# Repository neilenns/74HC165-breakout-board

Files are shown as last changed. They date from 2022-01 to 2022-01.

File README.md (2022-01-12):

# 74HC165 breakout board

This PCB provides access to the inputs of four serially connected 74HC165s. It's perfect for expanding the number
of inputs available on smaller Arduinos like the Pro Micro or Nano when building flight simulator components
that interact with [MobiFlight](http://www.mobiflight.com).

74HC165-breakout-board-3D_top

## Ordering from JLCPCB

These boards are ready to order from JLCPCB with their SMT fabrication service. You'll receive boards with all
the components soldered on except for the pin headers which you add yourself.

### Setting up the PCB details

1. Download and unpack `74HC165-breakout-board-JLCPCB.zip` from [the latest release](https://github.com/neilenns/74HC165-breakout-board/releases/latest). You will wind up with three files:

   - `74HC165-breakout-board-JLCPCB.zip`
   - `74HC165-breakout-board_bom_jlc.csv`
   - `74HC165-breakout-board_cpl_jlc.csv`

2. Start a new order with JLCPCB and upload the `74HC165-breakout-board-JLCPCB.zip` file for the Gerbers.
3. Set the `Surface Finish` option to `LeadFree HASL-RoHS`.
4. Set the `Remove Order Number` option to `Specify a location`.
5. Enable the `SMT Assembly` option.
6. Make sure `Assemble top side` is selected.
7. Set the `Tooling holes` option to `Added by customer`.
8. Agree to the terms and select the `Confirm` button.

### Setting up the SMT assembly

1. Upload the `74HC165-breakout-board_bom_jlc.csv` file for the BOM file.
2. Upload the `74HC165-breakout-board_bom_jlc` file for the CPL file.
3. Select the `Next` button.
4. Verify three parts are detected: `4D03WGJ0103T5E`, `CC0805KRX7R9BB104` and `74HC165D,653`. If you are ordering the default 5 boards
   you'll see order quantities of 50 for each part due to minimum part count requirements. This is expected.
5. Select the `Next` button.
6. Select the `Save to cart` button.

The total cost for five green PCBs with all parts assembled should be around $16.

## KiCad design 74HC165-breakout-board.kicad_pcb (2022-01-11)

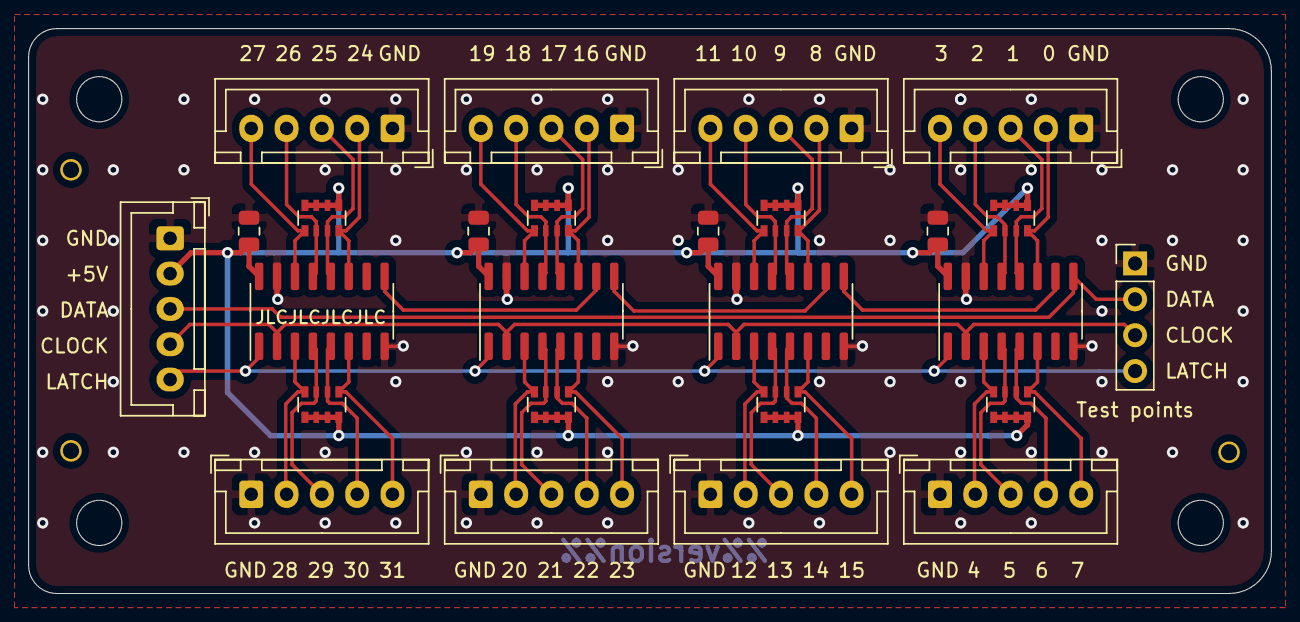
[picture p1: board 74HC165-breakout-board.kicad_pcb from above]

Board: 2 copper layers, 88.0 x 40.0 mm, 33 parts (0 on the bottom side), 40 nets.

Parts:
C1, C2, C3, C4: 100nF; C_0805_2012Metric
H1, H2, H3, H4: MountingHole; MountingHole_3.2mm_M3
H5, H6, H7: MountingHole; JLCPCB_Tooling_Hole
J1, J2, J3, J4, J5, J6, J7, J8, J9: Conn_01x05; JST_XH_B5B-XH-A_1x05_P2.50mm_Vertical
J10: Conn_01x04; PinHeader_1x04_P2.54mm_Vertical
RN1, RN2, RN3, RN4, RN5, RN6, RN7, RN8: R_Pack04; R_Array_Convex_4x0603
U1, U2, U3, U4: 74HC165; SOIC-16_3.9x9.9mm_P1.27mm

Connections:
+5V: C1.1, C2.1, C3.1, C4.1, J1.2, RN1.1, RN1.2, RN1.3, RN1.4, RN2.1, RN2.2, RN2.3, RN2.4, RN3.1, RN3.2, RN3.3, RN3.4, RN4.1, RN4.2, RN4.3, RN4.4, RN5.1, RN5.2, RN5.3, RN5.4, RN6.1, RN6.2, RN6.3, RN6.4, RN7.1, RN7.2, RN7.3, RN7.4, RN8.1, RN8.2, RN8.3, RN8.4, U1.16, U2.16, U3.16, U4.16
/74HC165/A: J2.2, RN1.8, U1.11
/74HC165/B: J2.3, RN1.7, U1.12
/74HC165/C: J2.4, RN1.6, U1.13
/74HC165/D: J2.5, RN1.5, U1.14
/74HC165/E: J3.2, RN2.8, U1.3
/74HC165/F: J3.3, RN2.7, U1.4
/74HC165/G: J3.4, RN2.6, U1.5
/74HC165/H: J3.5, RN2.5, U1.6
/74HC165/QH: U1.9, U2.10
/sheet61DDC3C2/A: J6.2, RN5.8, U3.11
/sheet61DDC3C2/B: J6.3, RN5.7, U3.12
/sheet61DDC3C2/C: J6.4, RN5.6, U3.13
/sheet61DDC3C2/D: J6.5, RN5.5, U3.14
/sheet61DDC3C2/E: J7.2, RN6.8, U3.3
/sheet61DDC3C2/F: J7.3, RN6.7, U3.4
/sheet61DDC3C2/G: J7.4, RN6.6, U3.5
/sheet61DDC3C2/H: J7.5, RN6.5, U3.6
/sheet61DDC3C2/QH: U3.9, U4.10
/sheet61DDC5EC/A: J8.2, RN7.8, U4.11
/sheet61DDC5EC/B: J8.3, RN7.7, U4.12
/sheet61DDC5EC/C: J8.4, RN7.6, U4.13
/sheet61DDC5EC/D: J8.5, RN7.5, U4.14
/sheet61DDC5EC/E: J9.2, RN8.8, U4.3
/sheet61DDC5EC/F: J9.3, RN8.7, U4.4
/sheet61DDC5EC/G: J9.4, RN8.6, U4.5
/sheet61DDC5EC/H: J9.5, RN8.5, U4.6
/sheet61DDC16C/A: J4.2, RN3.8, U2.11
/sheet61DDC16C/B: J4.3, RN3.7, U2.12
/sheet61DDC16C/C: J4.4, RN3.6, U2.13
/sheet61DDC16C/D: J4.5, RN3.5, U2.14
/sheet61DDC16C/E: J5.2, RN4.8, U2.3
/sheet61DDC16C/F: J5.3, RN4.7, U2.4
/sheet61DDC16C/G: J5.4, RN4.6, U2.5
/sheet61DDC16C/H: J5.5, RN4.5, U2.6
/sheet61DDC16C/QH: U2.9, U3.10
CLOCK: J1.4, J10.3, U1.2, U2.2, U3.2, U4.2
DATA: J1.3, J10.2, U4.9
GND: C1.2, C2.2, C3.2, C4.2, J1.1, J2.1, J3.1, J4.1, J5.1, J6.1, J7.1, J8.1, J9.1, J10.1, U1.8, U1.15, U2.8, U2.15, U3.8, U3.15, U4.8, U4.15
LATCH: J1.5, J10.4, U1.1, U2.1, U3.1, U4.1

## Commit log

2022-01-10 Initial version
    [74HC165-breakout-board.kicad_pcb, 74HC165-breakout-board.sch, 74HC165.sch]
2022-01-10 Add GND to each header, remove daisy chain
    [74HC165-breakout-board.kicad_pcb, 74HC165-breakout-board.sch, 74HC165.sch]
2022-01-10 Switch to footprints available at JLCPCB
    [74HC165-breakout-board.kicad_pcb, 74HC165.sch]
2022-01-10 Fix resistors, add tooling holes, add test points
    [74HC165-breakout-board.kicad_pcb, 74HC165-breakout-board.sch, 74HC165.sch]
2022-01-10 Add PCB measurements
    [74HC165-breakout-board.kicad_pcb]
2022-01-10 Add version and date stamps
    [74HC165-breakout-board.kicad_pcb]
2022-01-10 Try moving a bracket?
2022-01-10 Get rid of date and version from PCB page settings, add MF logo
    [74HC165-breakout-board.kicad_pcb]
2022-01-11 Add date and version back to PCB
    [74HC165-breakout-board.kicad_pcb]
2022-01-11 Add date back to PCB silkscreen
    [74HC165-breakout-board.kicad_pcb]
2022-01-11 Put ground on pin 1 of all the connectors Fixes #1
    [74HC165-breakout-board.kicad_pcb, 74HC165-breakout-board.sch, 74HC165.sch]
2022-01-11 Add pin numbers to back of board Fixes #3
    [74HC165-breakout-board.kicad_pcb]
2022-01-11 Make board previews MobiFlight blue Fixes #7
2022-01-11 Add via stitching Fixes #4
    [74HC165-breakout-board.kicad_pcb]
